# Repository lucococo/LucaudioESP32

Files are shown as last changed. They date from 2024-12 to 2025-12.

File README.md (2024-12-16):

View this project on [CADLAB.io](https://cadlab.io/project/28745). 

# LucaudioESP32

_Project inspired by [sonocotta ESP audio docks.](https://github.com/sonocotta/esp32-audio-dock/tree/main)_

I wanted a solution for wireless audio multiroom synchronized players, and the best I found was projects using [squeezelite-esp32](https://github.com/sle118/squeezelite-esp32).

I did my own board because firstly I wanted to improve my cad skills, and also because I like bringing my own personnal touch.
Project is still in development, I'm adding new features on my pcb later on

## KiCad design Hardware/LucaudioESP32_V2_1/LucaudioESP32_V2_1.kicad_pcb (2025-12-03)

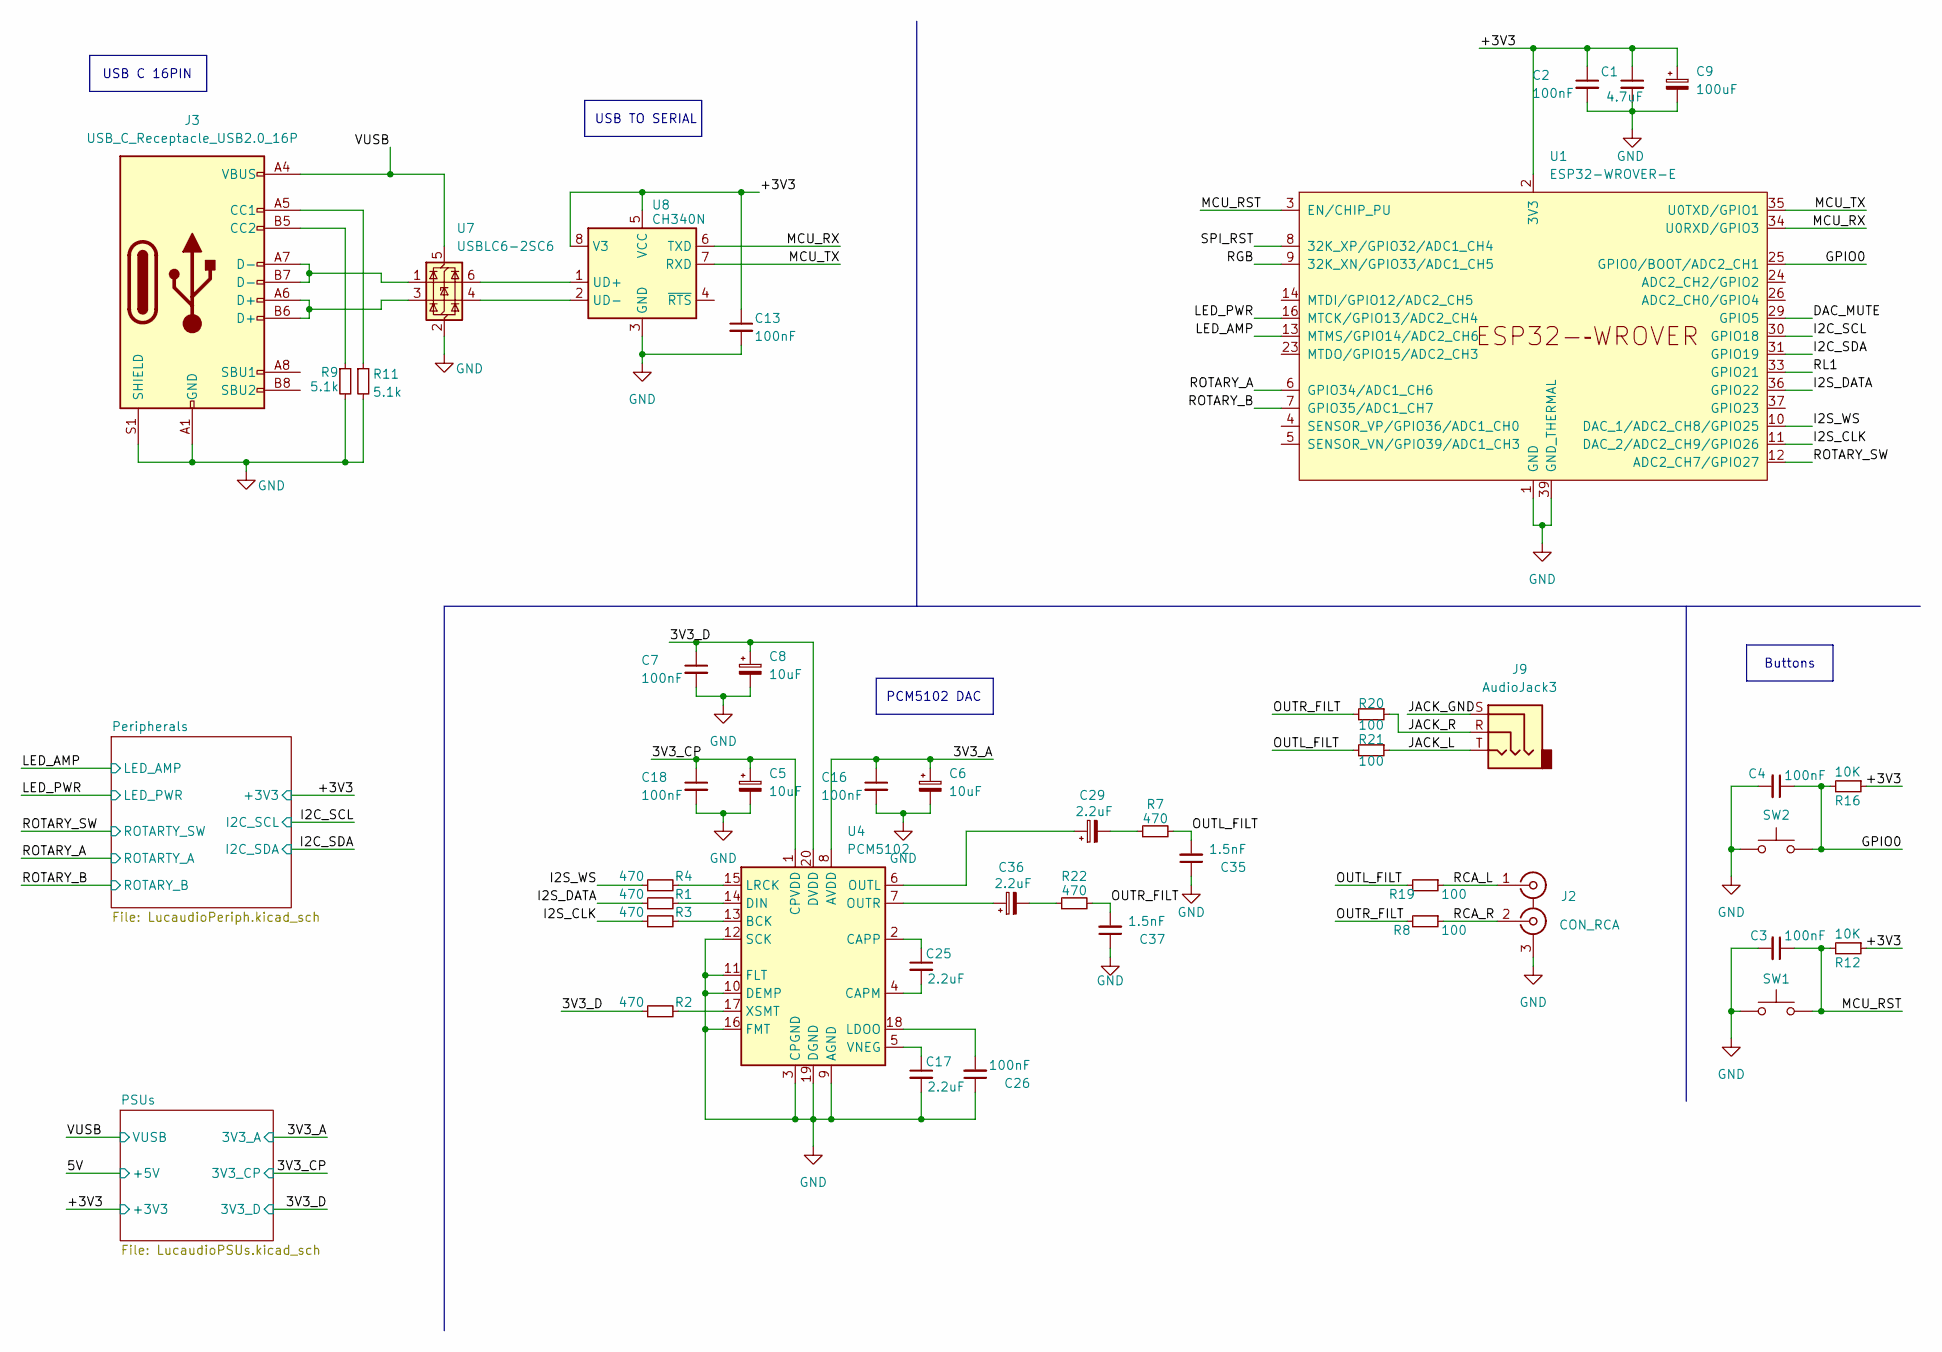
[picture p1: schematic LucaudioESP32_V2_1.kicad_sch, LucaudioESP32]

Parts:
C1: 4.7uF; C_0805_2012Metric_Pad1.18x1.45mm_HandSolder
C2, C7, C16, C18, C26: 100nF; C_0805_2012Metric_Pad1.18x1.45mm_HandSolder
C3, C4, C13: 100nF; C_0805_2012Metric
C5, C6, C8: 10uF; CP_Elec_5x4.5
C9: 100uF; CP_Elec_5x4.5
C17, C25: 2.2uF; C_0805_2012Metric_Pad1.18x1.45mm_HandSolder
C29, C36: 2.2uF; CP_EIA-3216-10_Kemet-I
C35, C37: 1.5nF; C_0805_2012Metric_Pad1.18x1.45mm_HandSolder
J2: CON_RCA; 2x RCA
J3: USB_C_Receptacle_USB2.0_16P; USB_C_Receptacle_G-Switch_GT-USB-7010ASV
J9: AudioJack3; JST_3p_audio
R1, R2, R3, R4, R7, R22: 470; R_0805_2012Metric_Pad1.20x1.40mm_HandSolder
R8, R19, R20, R21: 100; R_0805_2012Metric_Pad1.20x1.40mm_HandSolder
R9, R11: 5.1k; R_0805_2012Metric_Pad1.20x1.40mm_HandSolder
R12, R16: 10K; R_0805_2012Metric_Pad1.20x1.40mm_HandSolder
SW1, SW2: SW_Omron_B3FS; SW_SPST_Omron_B3FS-100xP
U1: ESP32-WROVER-E
U4: PCM5102; TSSOP-20_4.4x6.5mm_P0.65mm
U7: USBLC6-2SC6; SOT-23-6
U8: CH340N; SOP-8_3.9x4.9mm_P1.27mm

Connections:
/3V3_A: C6.1, C16.1, U4.8 (AVDD); also elsewhere on the board
/3V3_CP: C5.1, C18.1, U4.1 (CPVDD); also elsewhere on the board
/3V3_D: C7.1, C8.1, R2.1, U4.20 (DVDD); also elsewhere on the board
/+3V3: C1.1, C2.1, C9.1, C13.1, R12.1, R16.1, U1.2 (3V3), U8.5 (VCC), U8.8 (V3); also elsewhere on the board
/DAC_MUTE: U1.29 (GPIO5)
/GPIO0: C4.1, R16.2, SW2.2, U1.25 (GPIO0/BOOT/ADC2_CH1)
/I2C_SCL: U1.30 (GPIO18); also elsewhere on the board
/I2C_SDA: U1.31 (GPIO19); also elsewhere on the board
/I2S_CLK: R3.1, U1.11 (DAC_2/ADC2_CH9/GPIO26)
/I2S_DATA: R1.1, U1.36 (GPIO22)
/I2S_WS: R4.1, U1.10 (DAC_1/ADC2_CH8/GPIO25)
/JACK_GND: J9.S
/JACK_L: J9.T, R21.1
/JACK_R: J9.R, R20.1
/LED_AMP: U1.13 (MTMS/GPIO14/ADC2_CH6); also elsewhere on the board
/LED_PWR: U1.16 (MTCK/GPIO13/ADC2_CH4); also elsewhere on the board
/MCU_RST: C3.1, R12.2, SW1.2, U1.3 (EN/CHIP_PU)
/MCU_RX: U1.34 (U0RXD/GPIO3), U8.6 (TXD)
/MCU_TX: U1.35 (U0TXD/GPIO1), U8.7 (RXD)
/OUTL_FILT: C35.2, R7.2, R19.2, R21.2
/OUTR_FILT: C37.2, R8.2, R20.2, R22.2
/RCA_L: J2.1 (IN1), R19.1
/RCA_R: J2.2 (IN2), R8.1
/RGB: U1.9 (32K_XN/GPIO33/ADC1_CH5)
/RL1: U1.33 (GPIO21)
/ROTARY_A: U1.6 (GPIO34/ADC1_CH6); also elsewhere on the board
/ROTARY_B: U1.7 (GPIO35/ADC1_CH7); also elsewhere on the board
/ROTARY_SW: U1.12 (ADC2_CH7/GPIO27); also elsewhere on the board
/SPI_RST: U1.8 (32K_XP/GPIO32/ADC1_CH4)
/VUSB: J3.A4 (VBUS), J3.A9 (VBUS), J3.B4 (VBUS), J3.B9 (VBUS), U7.5 (VBUS); also elsewhere on the board
GND: C1.2, C2.2, C3.2, C4.2, C5.2, C6.2, C7.2, C8.2, C9.2, C13.2, C16.2, C17.2, C18.2, C26.1, C35.1, C37.1, J2.3 (EXT), J3.A1 (GND), J3.A12 (GND), J3.B1 (GND), J3.B12 (GND), J3.S1 (SHIELD), R9.2, R11.2, SW1.1, SW2.1, U1.1 (GND), U1.15 (GND), U1.38 (GND), U1.39 (GND_THERMAL), U4.3 (CPGND), U4.9 (AGND), U4.10 (DEMP), U4.11 (FLT), U4.12 (SCK), U4.16 (FMT), U4.19 (DGND), U7.2 (GND), U8.3 (GND); also elsewhere on the board
unnamed: C29.2, R7.1
unnamed: C36.2, R22.1
unnamed: J3.A5 (CC1), R11.1
unnamed: J3.B5 (CC2), R9.1
unnamed: J3.A6 (D+), J3.B6 (D+), U7.3 (I/O2)
unnamed: J3.A7 (D-), J3.B7 (D-), U7.1 (I/O1)
unnamed: R3.2, U4.13 (BCK)
unnamed: C25.2, U4.4 (CAPM)
unnamed: C25.1, U4.2 (CAPP)
unnamed: R1.2, U4.14 (DIN)
unnamed: C26.2, U4.18 (LDOO)
unnamed: R4.2, U4.15 (LRCK)
unnamed: C29.1, U4.6 (OUTL)
unnamed: C36.1, U4.7 (OUTR)
unnamed: C17.1, U4.5 (VNEG)
unnamed: R2.2, U4.17 (XSMT)
unnamed: U7.6 (I/O1), U8.1 (UD+)
unnamed: U7.4 (I/O2), U8.2 (UD-)

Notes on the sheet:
PCM5102 DAC
USB C 16PIN
Buttons
USB TO SERIAL

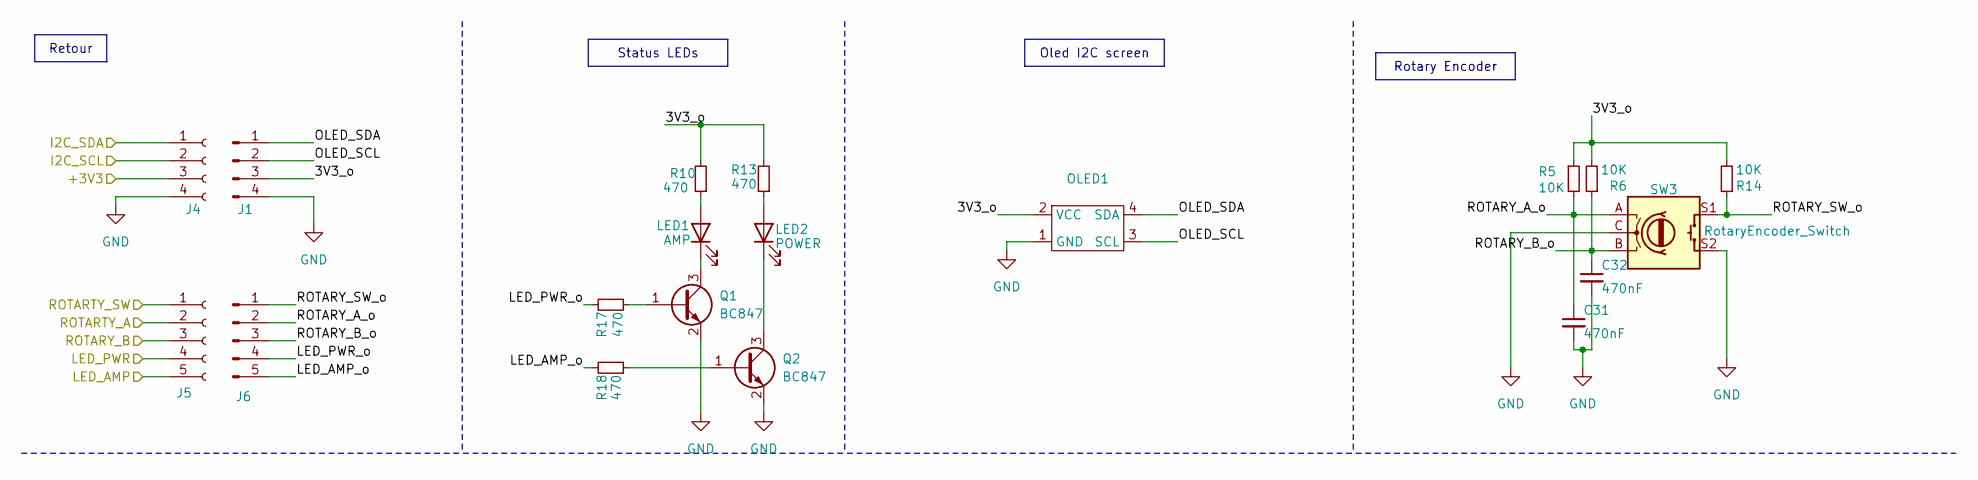
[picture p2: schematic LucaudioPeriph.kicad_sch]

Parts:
C31, C32: 470nF; C_0805_2012Metric_Pad1.18x1.45mm_HandSolder
J1: Conn_01x04_Pin; PinHeader_1x04_P2.54mm_Horizontal
J4: Conn_01x04_Socket; PinSocket_1x04_P2.54mm_Vertical
J5: Conn_01x05_Socket; PinSocket_1x05_P2.54mm_Vertical
J6: Conn_01x05_Pin; PinHeader_1x05_P2.54mm_Horizontal
LED1: AMP; LED_0805_2012Metric_Pad1.15x1.40mm_HandSolder
LED2: POWER; LED_0805_2012Metric_Pad1.15x1.40mm_HandSolder
OLED1: OLED_128_32
Q1, Q2: BC847; SOT-23
R5, R6, R14: 10K; R_0805_2012Metric_Pad1.20x1.40mm_HandSolder
R10, R13, R17, R18: 470; R_0805_2012Metric_Pad1.20x1.40mm_HandSolder
SW3: RotaryEncoder_Switch; RotaryEncoder_Alps_EC11E-Switch_Vertical_H20mm

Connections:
/+3V3: J4.3; also elsewhere on the board
/I2C_SCL: J4.2; also elsewhere on the board
/I2C_SDA: J4.1; also elsewhere on the board
/LED_AMP: J5.5; also elsewhere on the board
/LED_PWR: J5.4; also elsewhere on the board
/Peripherals/3V3_o: J1.3, OLED1.2 (VCC), R5.1, R6.2, R10.2, R13.2, R14.2
/Peripherals/LED_AMP_o: J6.5, R18.2
/Peripherals/LED_PWR_o: J6.4, R17.2
/Peripherals/OLED_SCL: J1.2, OLED1.3 (SCL)
/Peripherals/OLED_SDA: J1.1, OLED1.4 (SDA)
/Peripherals/ROTARY_A_o: C31.1, J6.2, R5.2, SW3.A
/Peripherals/ROTARY_B_o: C32.1, J6.3, R6.1, SW3.B
/Peripherals/ROTARY_SW_o: J6.1, R14.1, SW3.S1
/ROTARY_A: J5.2; also elsewhere on the board
/ROTARY_B: J5.3; also elsewhere on the board
/ROTARY_SW: J5.1; also elsewhere on the board
GND: C31.2, C32.2, J1.4, J4.4, OLED1.1 (GND), Q1.2 (E), Q2.2 (E), SW3.C, SW3.S2; also elsewhere on the board
unnamed: LED1.2 (A), R10.1
unnamed: LED1.1 (K), Q1.3 (C)
unnamed: LED2.2 (A), R13.1
unnamed: LED2.1 (K), Q2.3 (C)
unnamed: Q1.1 (B), R17.1
unnamed: Q2.1 (B), R18.1

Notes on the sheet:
Oled I2C screen
Rotary Encoder
Retour
Status LEDs

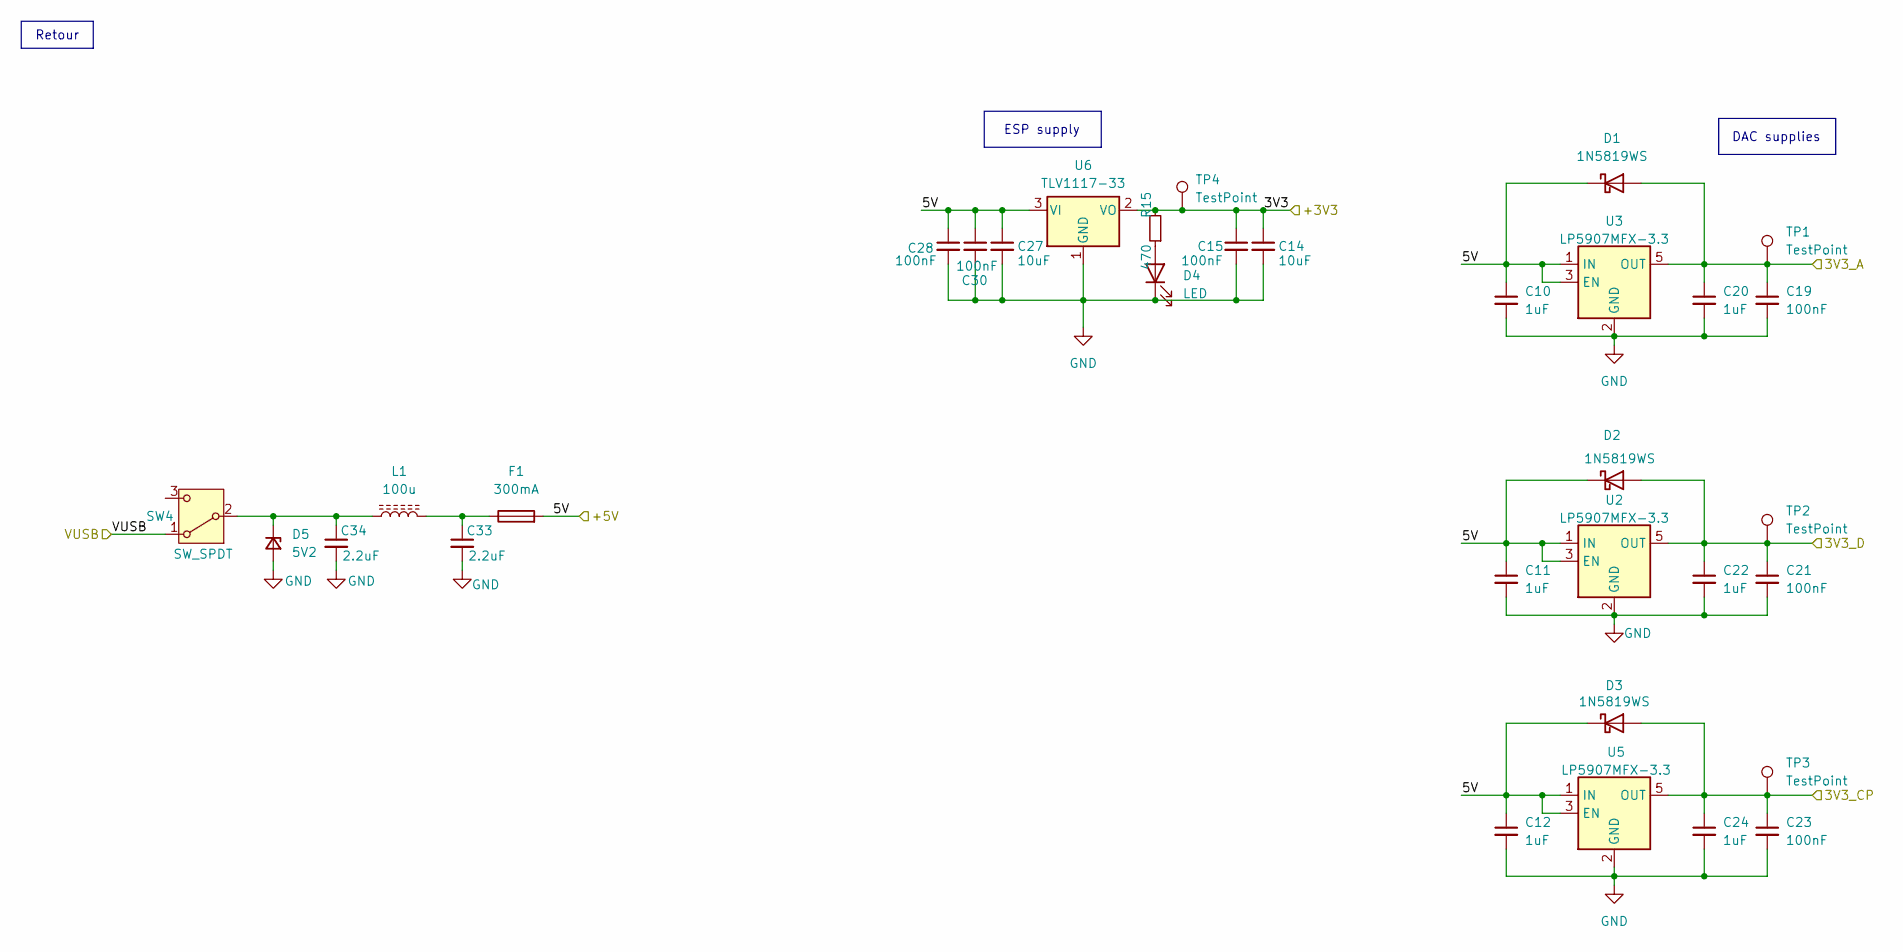
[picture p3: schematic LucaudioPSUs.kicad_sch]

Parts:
C10, C11, C12, C20, C22, C24: 1uF; C_0805_2012Metric
C14, C27: 10uF; C_0805_2012Metric
C15, C19, C21, C23, C28, C30: 100nF; C_0805_2012Metric
C33, C34: 2.2uF; C_0805_2012Metric_Pad1.18x1.45mm_HandSolder
D1, D2, D3: 1N5819WS; D_SOD-323_HandSoldering
D4: LED; LED_0805_2012Metric_Pad1.15x1.40mm_HandSolder
D5: 5V2; D_SMA
F1: 300mA; Fuse_0805_2012Metric
L1: 100u; L_Sunlord_SWPA4018S
R15: 470; R_0805_2012Metric_Pad1.20x1.40mm_HandSolder
SW4: SW_SPDT; Slide_angular_SPDT
TP1, TP2, TP3, TP4: TestPoint; TestPoint_Pad_1.0x1.0mm
U2, U3, U5: LP5907MFX-3.3; SOT-23-5
U6: TLV1117-33; SOT-223-3_TabPin2

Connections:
/3V3_A: C19.1, C20.1, D1.2 (A), TP1.1, U3.5 (OUT); also elsewhere on the board
/3V3_CP: C23.1, C24.1, D3.2 (A), TP3.1, U5.5 (OUT); also elsewhere on the board
/3V3_D: C21.1, C22.1, D2.2 (A), TP2.1, U2.5 (OUT); also elsewhere on the board
/5V: C10.1, C11.1, C12.1, C27.1, C28.1, C30.1, D1.1 (K), D2.1 (K), D3.1 (K), F1.2, U2.1 (IN), U2.3 (EN), U3.1 (IN), U3.3 (EN), U5.1 (IN), U5.3 (EN), U6.3 (VI)
/+3V3: C14.1, C15.1, R15.2, TP4.1, U6.2 (VO); also elsewhere on the board
/VUSB: SW4.1 (A); also elsewhere on the board
GND: C10.2, C11.2, C12.2, C14.2, C15.2, C19.2, C20.2, C21.2, C22.2, C23.2, C24.2, C27.2, C28.2, C30.2, C33.2, C34.2, D4.1 (K), D5.2 (A), U2.2 (GND), U3.2 (GND), U5.2 (GND), U6.1 (GND); also elsewhere on the board
unnamed: C33.1, F1.1, L1.2
unnamed: D4.2 (A), R15.1
unnamed: C34.1, D5.1 (K), L1.1, SW4.2 (B)

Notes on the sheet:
ESP supply
DAC supplies
Retour

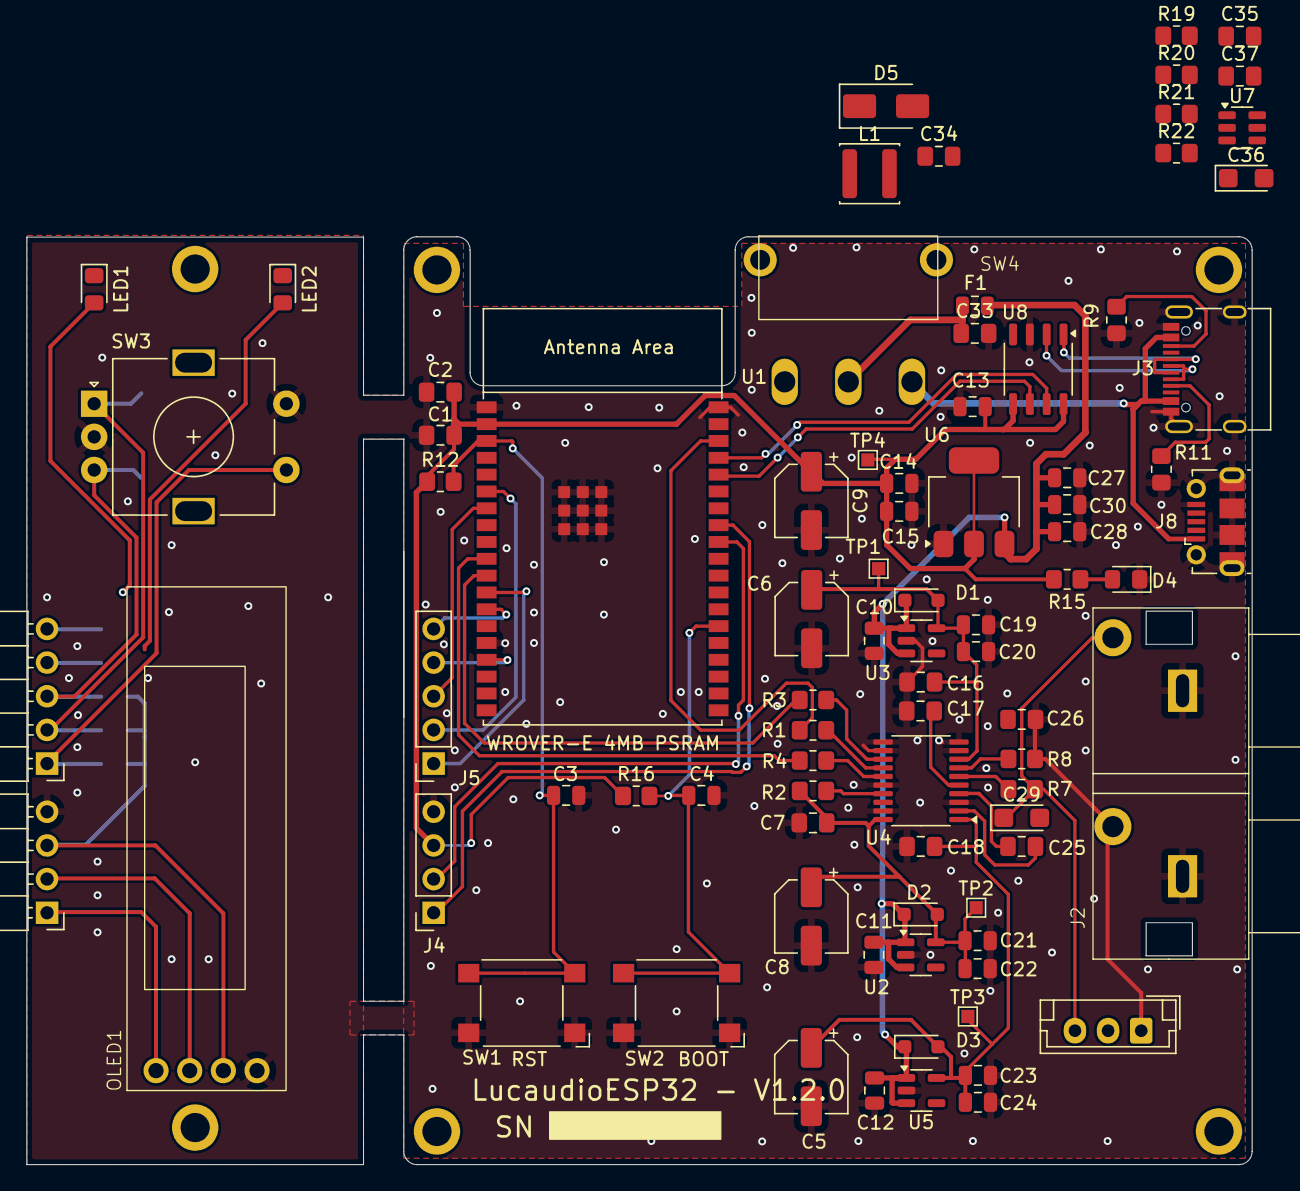
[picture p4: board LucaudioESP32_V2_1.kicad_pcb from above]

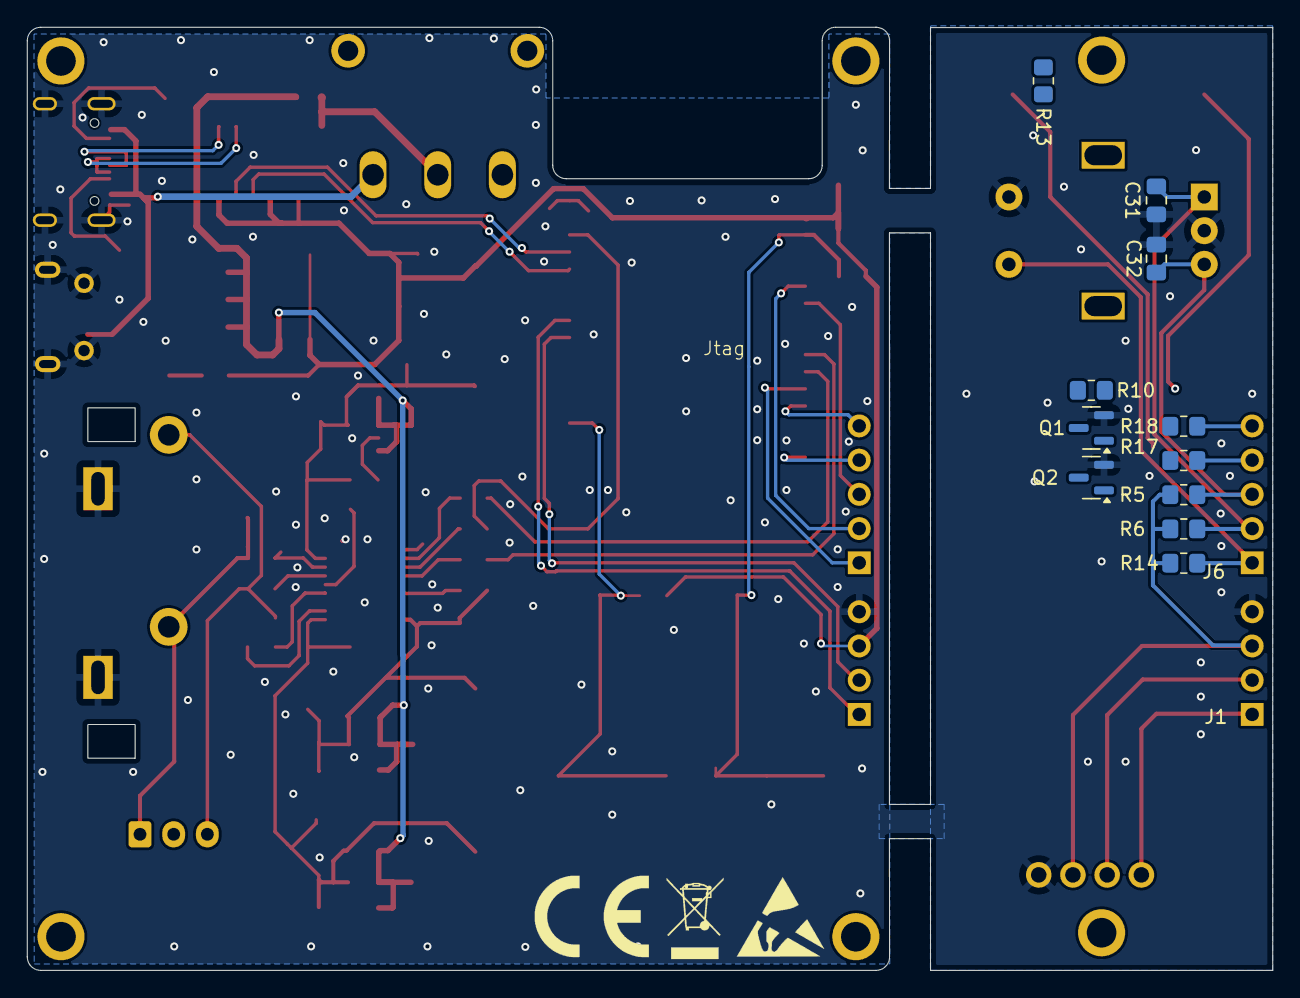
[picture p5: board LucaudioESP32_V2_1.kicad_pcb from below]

Board: 2 copper layers, 92.4 x 70.0 mm, 95 parts (11 on the bottom side), 62 nets.

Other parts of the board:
J8: USB_B_Micro; USB_Micro-B_Molex-105017-0001

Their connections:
GND: J8.5 (GND), J8.6 (Shield); also elsewhere on the board

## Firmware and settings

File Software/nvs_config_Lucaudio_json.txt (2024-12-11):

{
  "a2dp_ctmt": "1000",
  "a2dp_ctrld": "500",
  "a2dp_dev_name": "Lucaudio",
  "a2dp_sink_name": "SMSL BT4.2",
  "a2dp_spin": "0000",
  "actrls_config": "buttons",
  "airplay_name": "Lucaudio",
  "airplay_port": "5000",
  "ap_channel": "1",
  "ap_ip_address": "192.168.4.1",
  "ap_ip_gateway": "192.168.4.1",
  "ap_ip_netmask": "255.255.255.0",
  "ap_pwd": "squeezelite",
  "ap_ssid": "Lucaudio",
  "autoexec": "1",
  "autoexec1": "squeezelite -o I2S -b 500:2000 -d all=info -C 30 -W -n \"Lucaudio\"",
  "bat_config": "",
  "bt_name": "Lucaudio",
  "bt_sink_pin": "1234",
  "bt_sink_volume": "127",
  "buttons": "[{\"gpio\": 27,\"type\": \"BUTTON_LOW\",\"pull\": true,\"long_press\": 600,\"debounce\": 0,\"normal\": {\"pressed\": \"ACTRLS_TOGGLE\"},\"longpress\":{\"pressed\":\"ACTRLS_STOP\"}}]",
  "bypass_wm": "0",
  "cspot_config": "{\"deviceName\":\"Lucaudio\",\"bitrate\":160,\"zeroConf\":1}",
  "dac_config": "model=I2S,bck=26,ws=25,do=22",
  "dac_controlset": "",
  "dhcp_tmout": "8",
  "display_config": "I2C,width=128,height=32,address=60,driver=SSD1306,rotate",
  "enable_airplay": "1",
  "enable_bt_sink": "1",
  "enable_cspot": "1",
  "equalizer": "0,0,0,0,0,0,0,0,0,0",
  "eth_config": "",
  "ethtmout": "8",
  "gpio_exp_config": "",
  "host_name": "Lucaudio",
  "i2c_config": "scl=18,sda=19,speed=100000,port=0",
  "jack_mutes_amp": "n",
  "led_amp": "12",
  "led_brightness": "",
  "led_power": "13",
  "led_vu_config": "",
  "lms_ctrls_raw": "n",
  "loudness": "2",
  "metadata_config": "",
  "model_config": "",
  "ota_erase_blk": "249856",
  "ota_prio": "6",
  "ota_stack": "10240",
  "pollmin": "15",
  "pollmx": "600",
  "rel_api": "https://api.github.com/repos/sle118/squeezelite-esp32/releases",
  "release_url": "CONFIG_SQUEEZELITE_ESP32_RELEASE_URL",
  "rotary_config": "A=35,B=34,volume",
  "rotenc_gpio_a": "34",
  "rotenc_gpio_b": "35",
  "rotenc_gpio_btn": "27",
  "rotenc_mode": "volume",
  "rotenc_steps": "4",
  "set_GPIO": "13=power,12=amp",
  "sleep_config": "",
  "spdif_config": "",
  "spi_config": "",
  "stats": "n",
  "target": "",
  "telnet_block": "500",
  "telnet_buffer": "40000",
  "telnet_enable": ""
}

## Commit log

2024-07-24 Initial commit of KiCad project
    [BOM.xlsx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]
2024-12-11 Revamping folders
    [BOM.xlsx, LucaudiOptions.kicad_sch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]
2024-12-11 Add nvs parameters json
    [nvs_config_Lucaudio_json.txt]
2024-12-16 Update of V1.2.0
    [LucaudiOptions.kicad_sch, LucaudioESP32_V1_2_0.kicad_pcb, LucaudioESP32_V1_2_0.kicad_sch]
2024-12-16 Added I2C screen, rotary encoder and led status
2025-11-18 Revamping folders and added 2.0 and 2.1 on git
    [LucaudiOptions.kicad_sch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]
